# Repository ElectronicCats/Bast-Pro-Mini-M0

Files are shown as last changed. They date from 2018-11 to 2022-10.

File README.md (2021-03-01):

# Bast Pro Mini M0

MX0005

**[OSHW] MX0005 | Certified open source hardware |** [oshwa.org/cert.](https://www.oshwa.org/cert)

<a href="https://electroniccats.com/store/bast-pro-mini-m0/">
  
</a>

Electronic Cats Bast are a complete line of development boards for electronic cats.

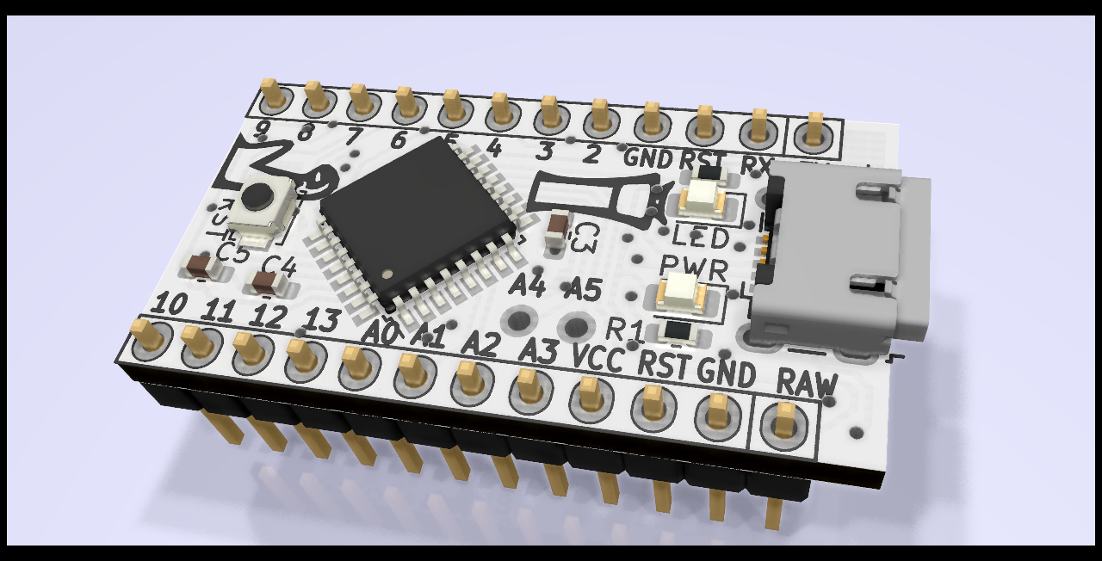
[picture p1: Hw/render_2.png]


Bast Pro Mini M0 is all the best in the world Arduino Pro Mini with a SAMD21 M0+ core, 32 bits of power!, Arduino pro mini pin to pin compatible with a micro USB port.

Electronic Cats invests time and resources providing this open source design, please support Electronic Cats and open-source hardware by purchasing products from Electronic Cats!

Designed by Electronic Cats.

## Installation

While the SAMD21 alone is powerful enough, what truly makes it special is its growing support in the Arduino IDE. With just a couple click's, copies, and pastes, you can add ARM Cortex-M0+-support to your Arduino IDE. 

First of all we'll need to install the Arduino SAMD based boards, to do it you just need to go (Tools > Board > Boards Manager...)

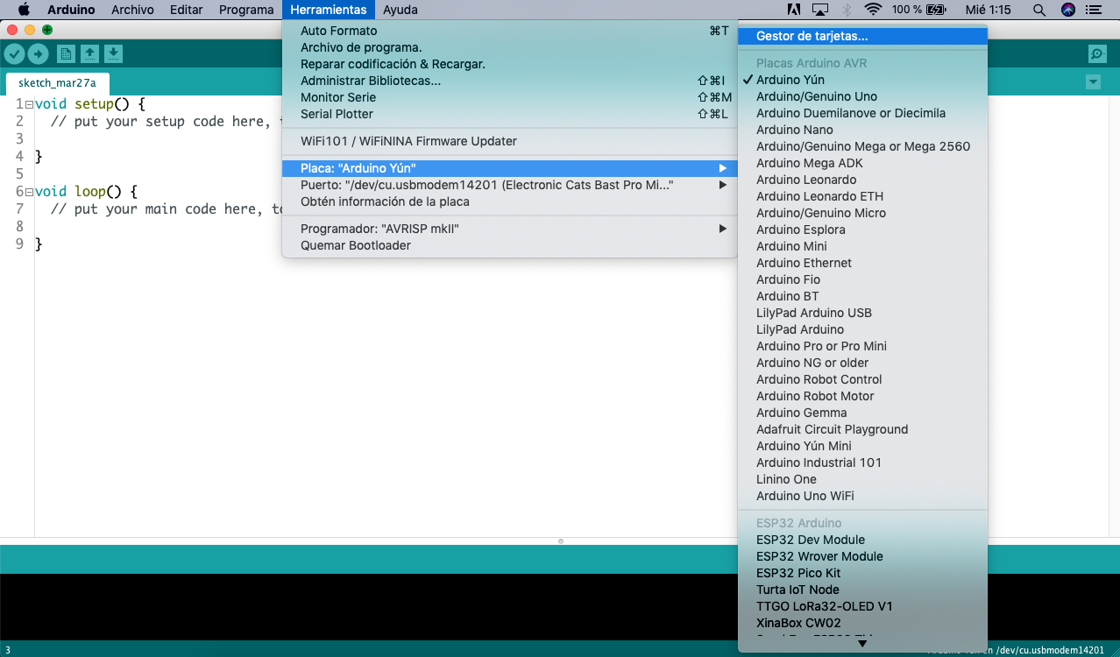
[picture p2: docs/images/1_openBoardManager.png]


And then search for "SAMD"

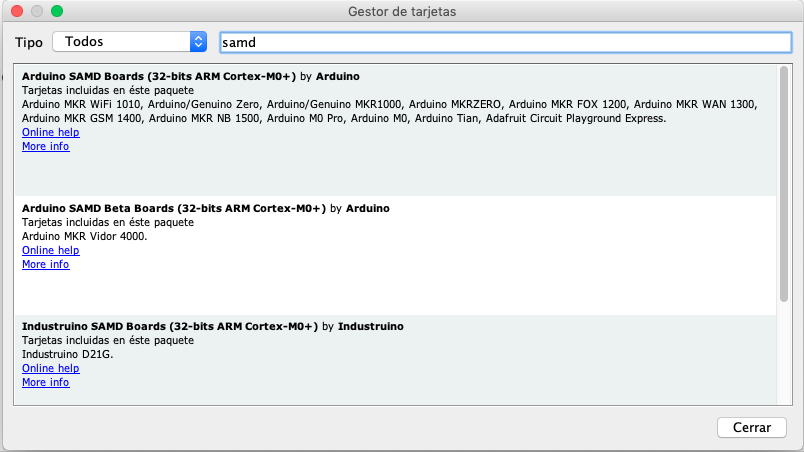
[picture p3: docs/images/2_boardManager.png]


And install the "Arduino SAMD Board (32-bits ARM Cortex M0+)" once you have installed the Arduino SAMD21 core you must proceed installing our boards variants following the next steps:

Open your Arduino preferences (File > Preferences) or (Arduino > Preferences)

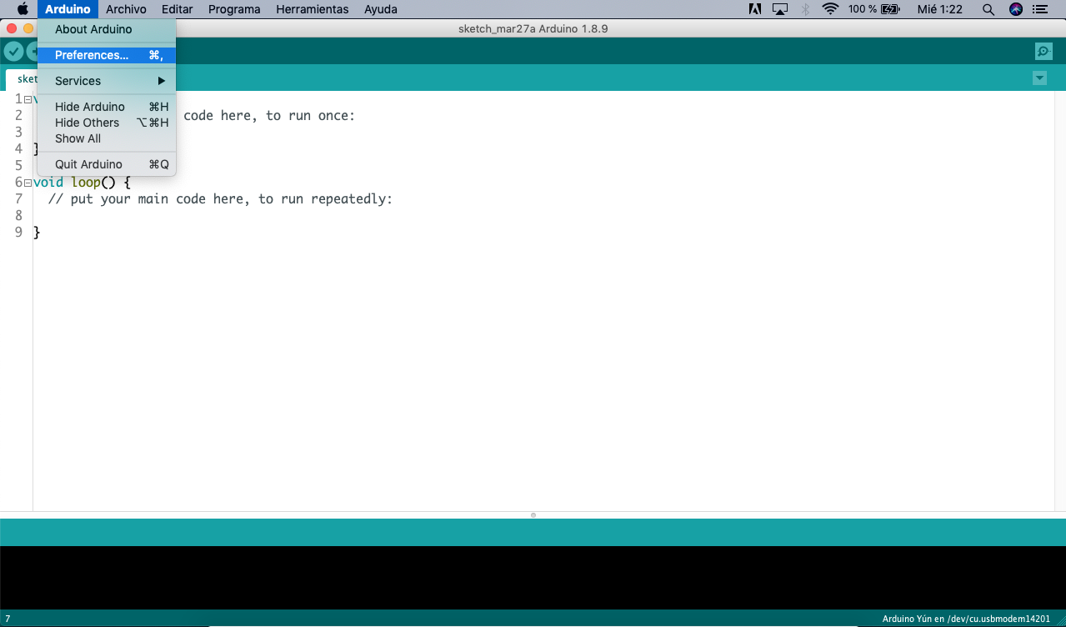
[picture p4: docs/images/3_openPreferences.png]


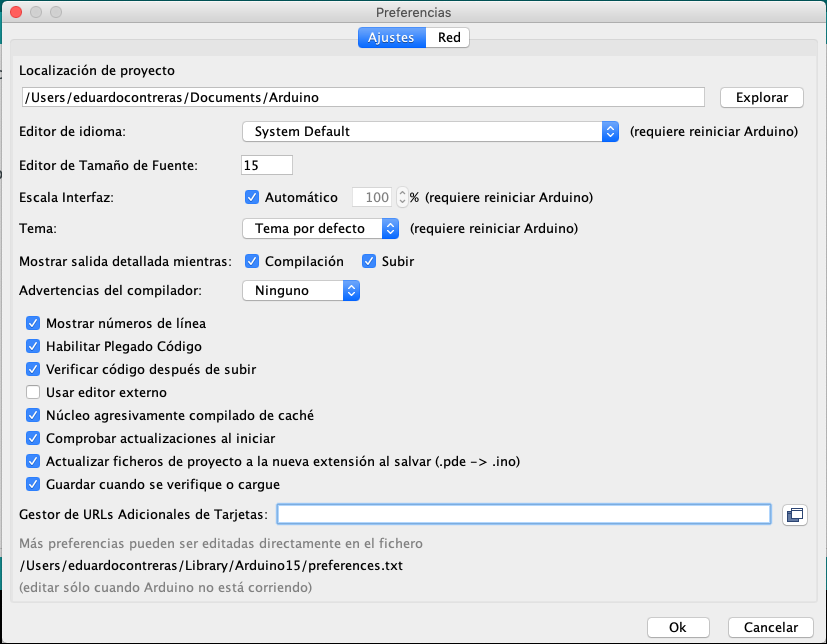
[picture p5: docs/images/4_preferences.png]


You will need to copy the next link into the additional boards manager URL, if you have another link just add a "," before this second link.

`https://electroniccats.github.io/Arduino_Boards_Index/package_electroniccats_index.json
`
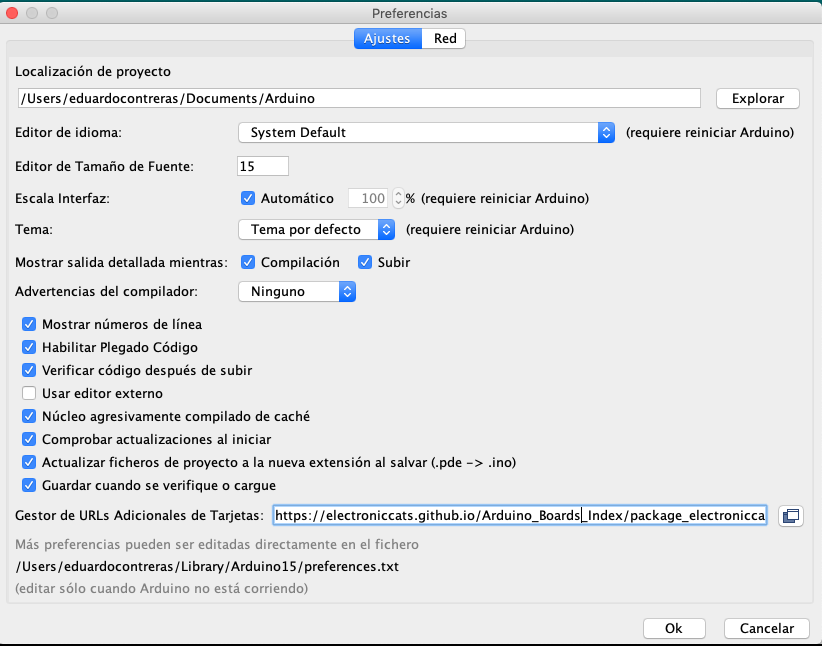
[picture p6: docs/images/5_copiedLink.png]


Then you can click on the OK button to close the preferences panel and continue the installation.

If you did hit "OK", travel back to the Board Manager menu. You should be able to find a new entry for Electronic Cats. If you don't see it, close the board manager and open it again.

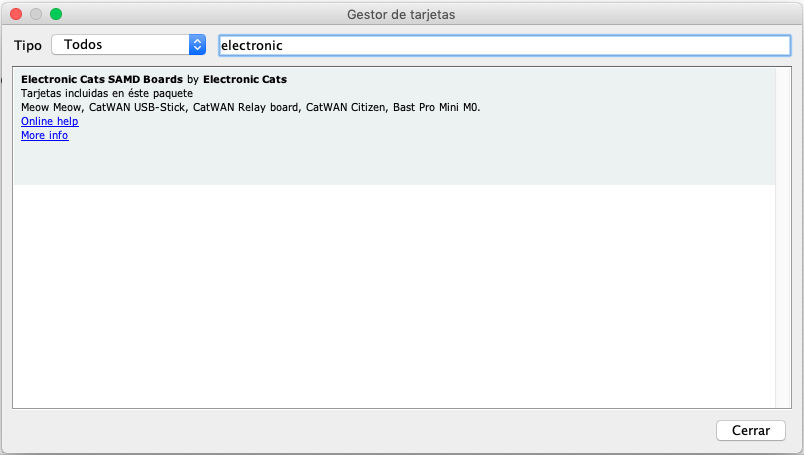
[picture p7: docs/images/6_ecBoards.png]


Click on install and once the boards are installed you should be able to select them on the (Tools > Boards) section.

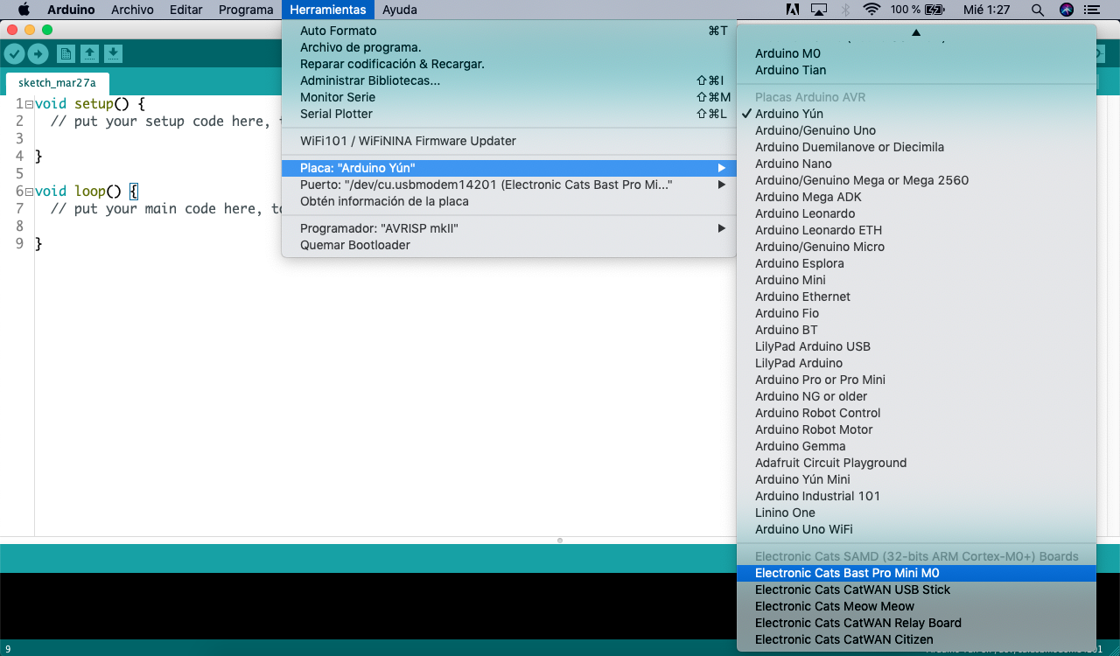
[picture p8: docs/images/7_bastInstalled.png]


So now you can program your Bast Pro Mini M0 as a common arduino!

Test the Blink example and then start prototyping!  

## Driver for windows 7 and 8.1

Zadig image

[Zadig](https://zadig.akeo.ie/) is the recommended tool to install drivers in Windows. The bootloader (4348,55E0) should be installed with WinUSB or libusb-win32 driver.

You can use USB Serial (CDC) driver for default CDC USB stack. If you tried to emulate another type of USB device without changing the PID/VID, you may need to uninstall the device before installing a new driver.

## Pinout

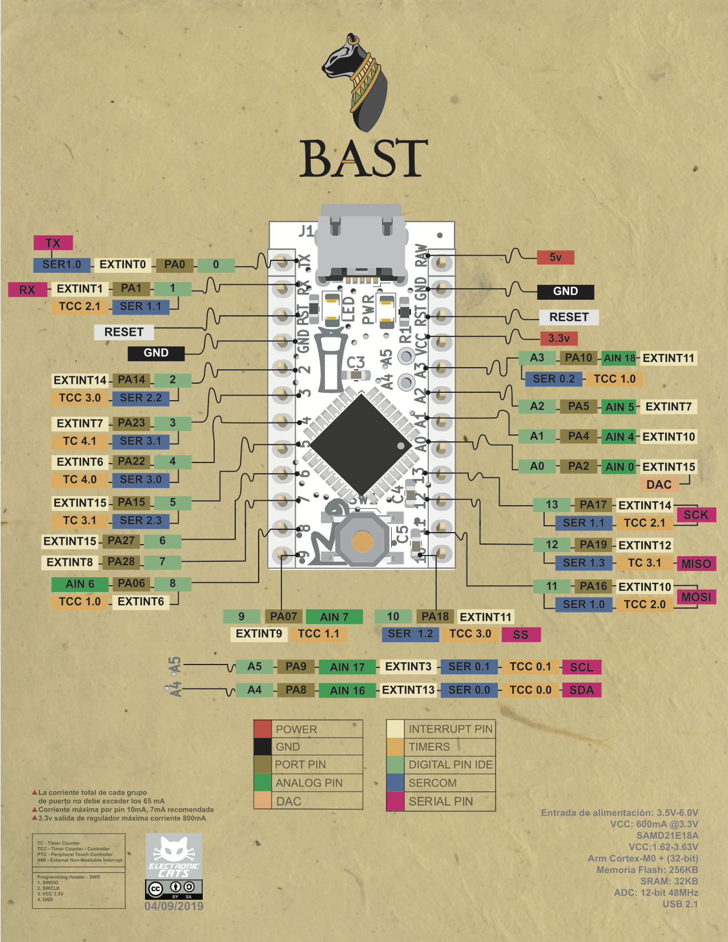
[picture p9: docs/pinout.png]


## License hardware

Hardware released under an CERN Open Hardware Licence v1.2. See the LICENSE_HARDWARE file for more information.

## License Documentation 
<br />Esta obra está bajo una <a rel="license" href="http://creativecommons.org/licenses/by-sa/4.0/">Licencia Creative Commons Atribución-CompartirIgual 4.0 Internacional</a>.

Electronic Cats is a registered trademark, please do not use if you sell these PCBs.

30 Oct 2018

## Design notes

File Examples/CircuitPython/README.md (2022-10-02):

## Ejemplos de codigo en CircuitPython

### Todos los ejemplos estan optimizados para la tarjeta:

## Bast Pro Mini M0.

* blink.py : Enciende y apaga el Led incroporado en la tarjeta.
* i2c_show.py : Muestra todos los pines que pueden ser usados para i2c
* pinout_show.py : Muestra los pines disponibles en la tarjeta.
* uart_show.py : Muestra todos los pines que pueden ser usados para UART.

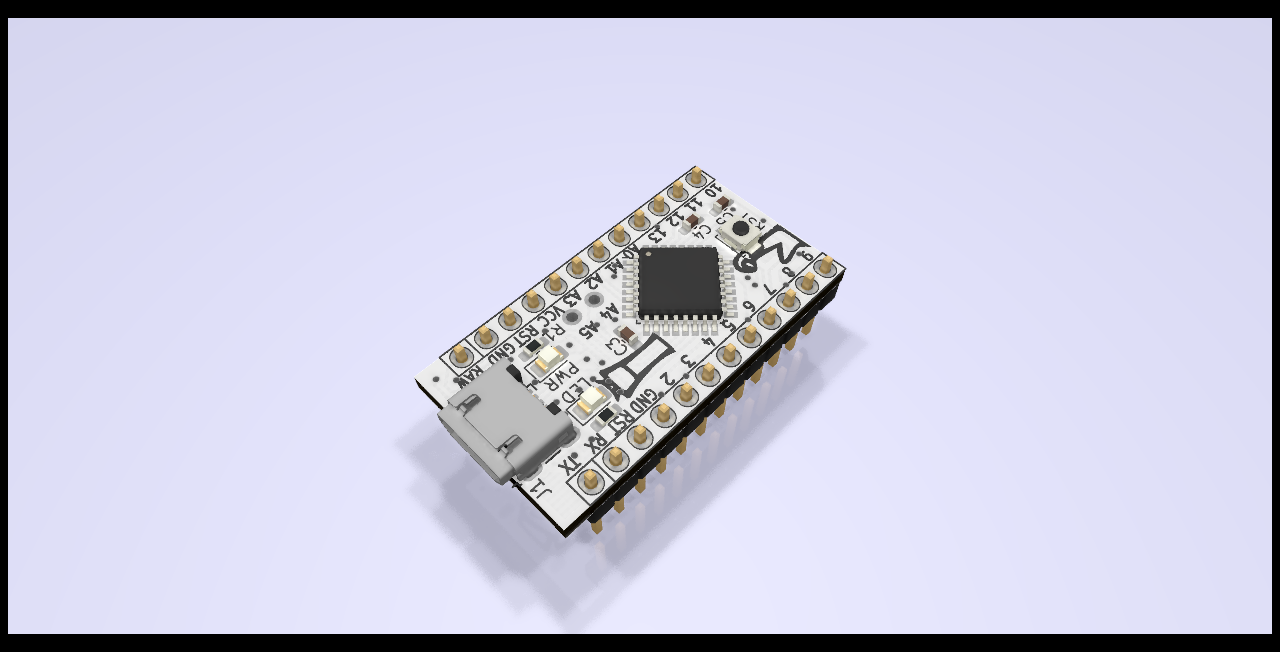
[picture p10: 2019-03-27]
Hw/render_1.png

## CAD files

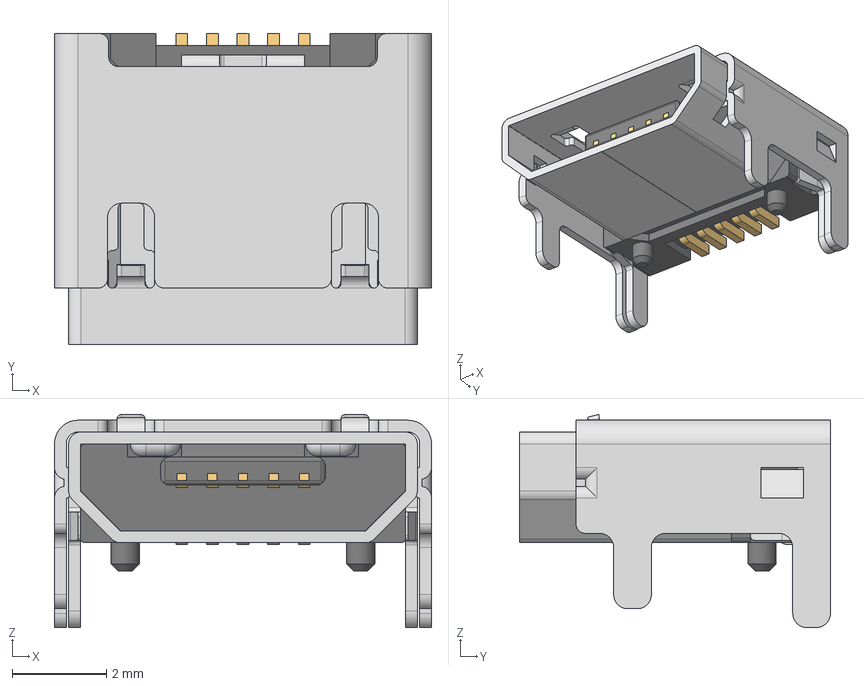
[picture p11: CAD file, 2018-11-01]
Hw/3d/629105150521 (rev1).stp
8.00 x 6.60 x 4.52 mm
629105150521_Housing
629105150521_Pin1 x 4
629105150521_Pin2
629105150521_Shielding2
629105150521_Shielding

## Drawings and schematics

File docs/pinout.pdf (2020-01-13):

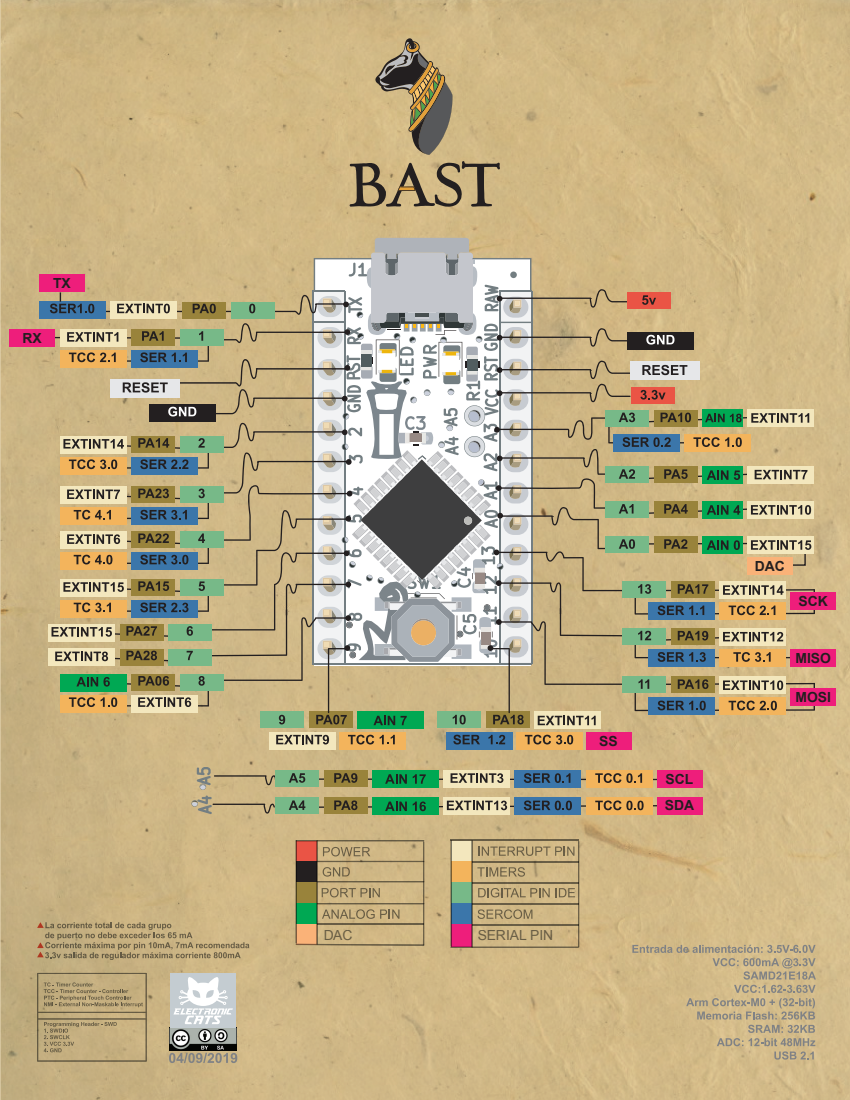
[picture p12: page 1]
SERIAL PIN; SDA; SCL; MISO; SCK; MOSI; DAC

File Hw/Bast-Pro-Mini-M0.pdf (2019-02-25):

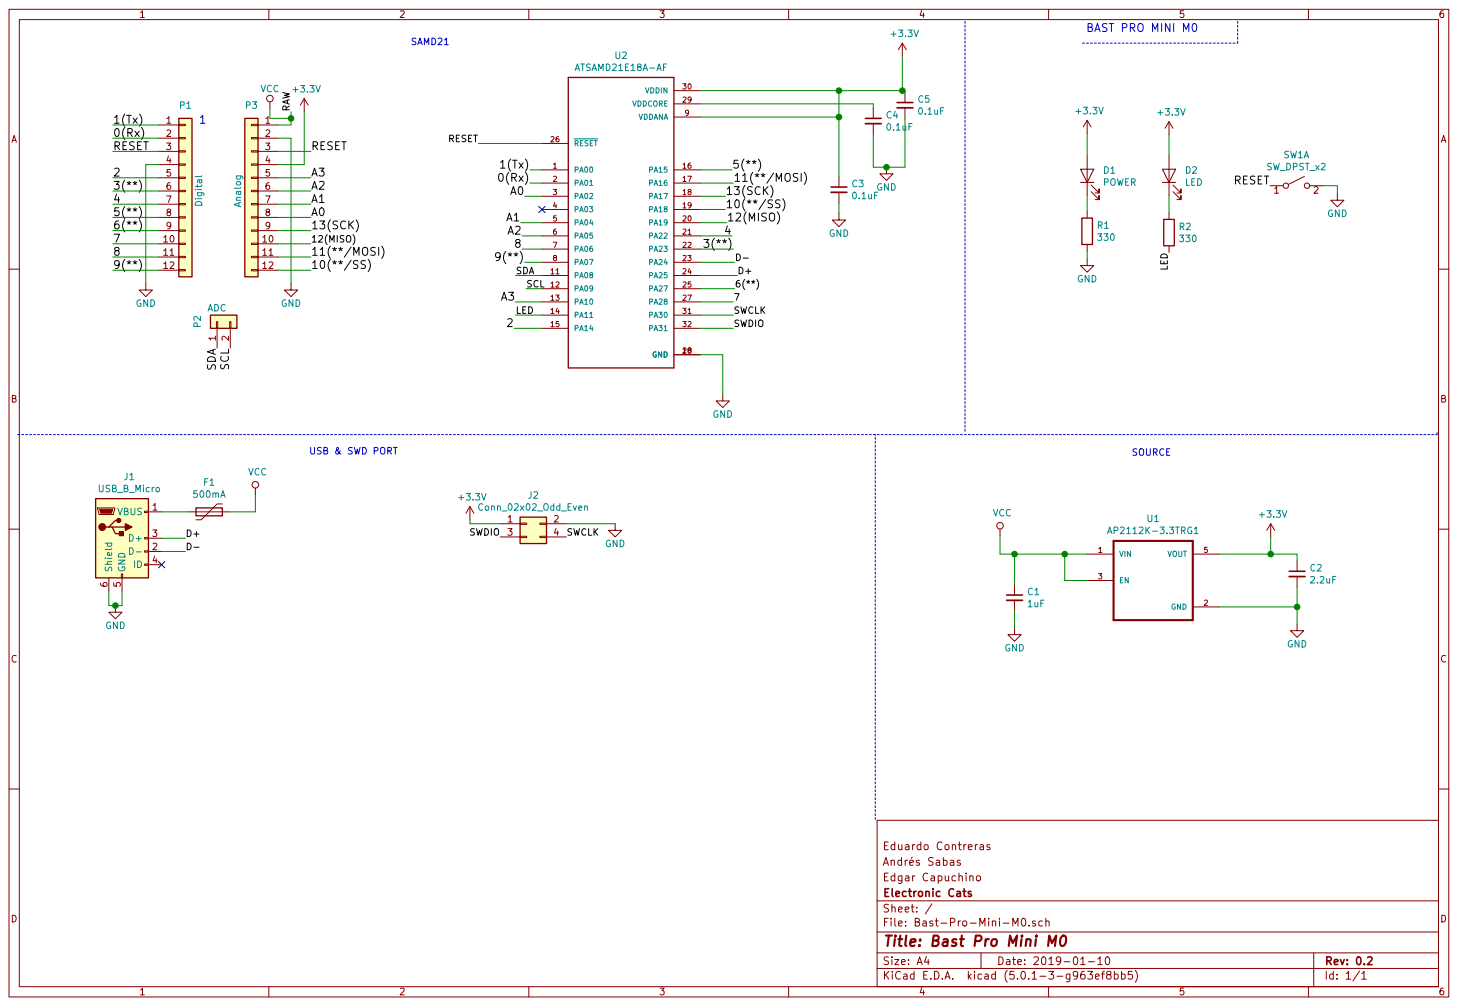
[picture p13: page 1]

12(MISO) 13(SCK) A0A1A2A3 SDA SCL

File: Bast-Pro-Mini-M0.sch Sheet: / Electronic Cats Edgar Capuchino Andrés Sabas Eduardo Contreras

Id: 1/1 Title: Bast Pro Mini M0

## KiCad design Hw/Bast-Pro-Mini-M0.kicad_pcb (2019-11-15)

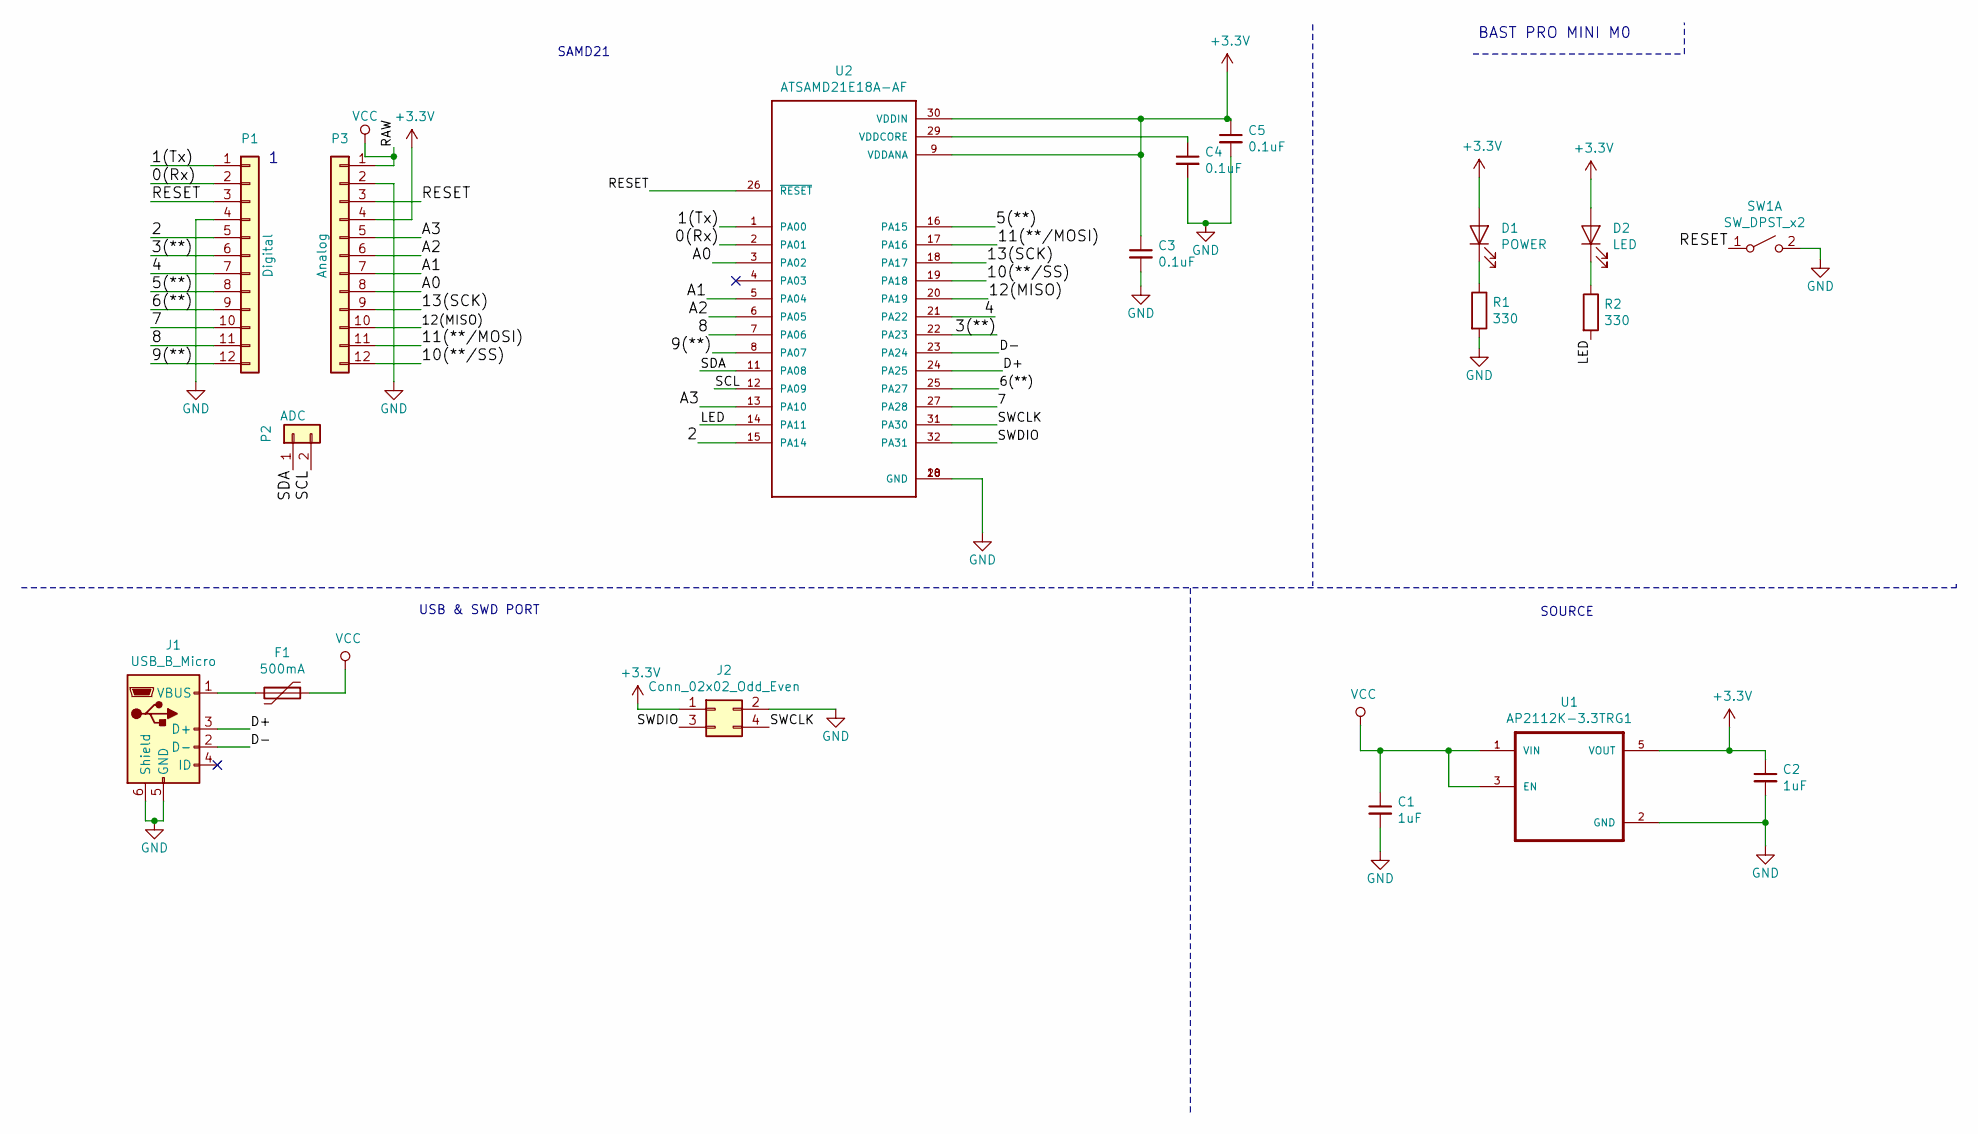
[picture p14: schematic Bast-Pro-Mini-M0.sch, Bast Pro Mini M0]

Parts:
C1, C2: 1uF; C_0603_1608Metric_Pad1.05x0.95mm_HandSolder
C3, C4, C5: 0.1uF; C_0603_1608Metric_Pad1.05x0.95mm_HandSolder
D1: POWER; LED_0805_2012Metric_Pad1.15x1.40mm_HandSolder
D2: LED; LED_0805_2012Metric_Pad1.15x1.40mm_HandSolder
F1: 500mA; Fuse_0805_2012Metric_Pad1.15x1.40mm_HandSolder
J1: USB_B_Micro; U254051N4BH806
J2: Conn_02x02_Odd_Even; PinHeader_2x02_P2.54mm_Vertical_SMD
P1: Digital; PinHeader_1x12_P2.54mm_Vertical
P2: ADC; Socket_Strip_Arduino_1x02
P3: Analog; Socket_Strip_Arduino_1x12
R1, R2: 330; R_0603_1608Metric_Pad1.05x0.95mm_HandSolder
SW1: SW_DPST_x2; SW_SPST_TL3342
U1: AP2112K-3.3TRG1; SOT-23-5
U2: ATSAMD21E18A-AF; TQFP-32_7x7mm_P0.8mm

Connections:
+3V3: C2.1, C3.1, C5.1, D1.2 (A), D2.2 (A), J2.1, P3.4, U1.5 (VOUT), U2.9 (VDDANA), U2.30 (VDDIN)
/0(Rx): P1.2, U2.2 (PA01)
/1(Tx): P1.1, U2.1 (PA00)
/2: P1.5, U2.15 (PA14)
/3(**): P1.6, U2.22 (PA23)
/4: P1.7, U2.21 (PA22)
/5(**): P1.8, U2.16 (PA15)
/6(**): P1.9, U2.25 (PA27)
/7: P1.10, U2.27 (PA28)
/8: P1.11, U2.7 (PA06)
/9(**): P1.12, U2.8 (PA07)
/10(**/SS): P3.12, U2.19 (PA18)
/11(**/MOSI): P3.11, U2.17 (PA16)
/12(MISO): P3.10, U2.20 (PA19)
/13(SCK): P3.9, U2.18 (PA17)
/A0: P3.8, U2.3 (PA02)
/A1: P3.7, U2.5 (PA04)
/A2: P3.6, U2.6 (PA05)
/A3: P3.5, U2.13 (PA10)
/D+: J1.3 (D+), U2.24 (PA25)
/D-: J1.2 (D-), U2.23 (PA24)
/LED: R2.2, U2.14 (PA11)
/RESET: P1.3, P3.3, SW1.1 (A), U2.26 (~RESET~)
/SCL: P2.2, U2.12 (PA09)
/SDA: P2.1, U2.11 (PA08)
/SWCLK: J2.4, U2.31 (PA30)
/SWDIO: J2.3, U2.32 (PA31)
GND: C1.2, C2.2, C3.2, C4.2, C5.2, J1.5 (GND), J1.6 (Shield), J2.2, P1.4, P3.2, R1.2, SW1.2 (B), U1.2 (GND), U2.10 (GND), U2.28 (GND)
unnamed: C4.1, U2.29 (VDDCORE)
unnamed: D1.1 (K), R1.1
unnamed: D2.1 (K), R2.1
unnamed: F1.2, J1.1 (VBUS)
VCC: C1.1, F1.1, P3.1, U1.1 (VIN), U1.3 (EN)

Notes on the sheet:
BAST PRO MINI M0
SAMD21
SOURCE
USB & SWD PORT

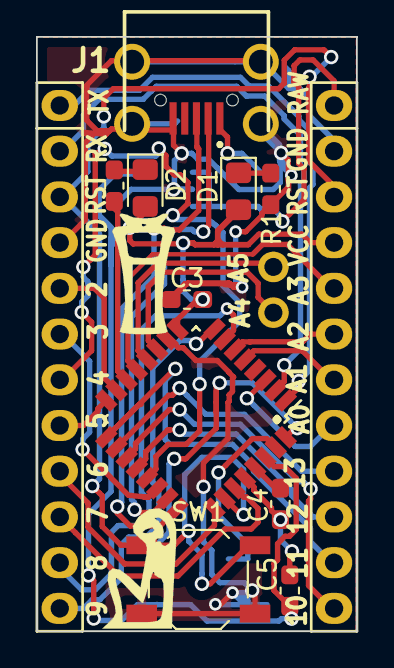
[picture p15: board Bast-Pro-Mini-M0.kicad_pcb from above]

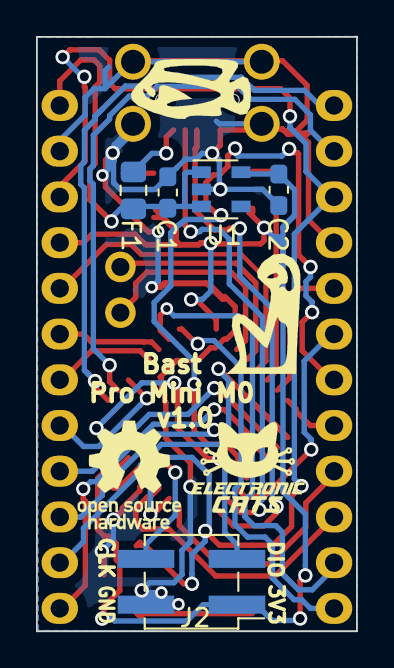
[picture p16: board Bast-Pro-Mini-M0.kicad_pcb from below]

Board: 2 copper layers, 17.8 x 33.0 mm, 18 parts (5 on the bottom side), 33 nets.

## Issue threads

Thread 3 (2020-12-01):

Windows 8.1 no reconoce la tarjeta Bast-Pro-Mini-M0

AngelBNShark, 2020-12-01:
Hola que tal tengo el siguiente conflicto: Al conectar la tarjeta Bast-Pro-Mini-M0 por cualquiera de los puertos USB este lo detecta pero aparece en la seccion de otros dispositivos con un triangulo amarillo y un signo de admiracion, obviamente esto significa que el driver no se instalo, me pueden apoyar para darle solucion a este problema.
Sera que habra que modificar el driver instalado en el ATSAMD21E18 o reconfigurarlo?
Este cambio se puede hacer desde el mismo puerto USB o se tiene que usar el puerto JTAG?

Bueno abro el hilo para dar solucion a esto.
Saludos!
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

sabas1080, 2020-12-01:
Hola @AngelBNShark

Windows 8.1 parece tener bastantes problemas con drivers en general, parece puede ser la firma de drivers segun este hilo, por favor probar y me cuentas https://forum.arduino.cc/index.php?topic=445796.0

AngelBNShark, 2020-12-02:
Gracias por tu respuesta, leó, implemento y comento ;)

AngelBNShark, 2020-12-02:
Hola @sabas1080

segui el procedimiento del link que me compartiste: desactive la firma de controladores de windows, re-instale el paquete de Arduino SAM Boards, conecte la bast pro mini y naranjas, sigue igual :(

sabas1080, 2020-12-02:
@AngelBNShark debes reinstalar arduino IDE y los drivers

sabas1080, 2020-12-02:
@AngelBNShark puedes probar usando https://zadig.akeo.ie/ ? Si no tendras que esperar a que generemos los drivers para Windows 8.1 y versiones pasadas

AngelBNShark, 2020-12-02:
Hola, hoy la conecte a una pc con Windows 7 y tampoco lo instaló.

Unas preguntas:
En que sistemas operativos la han probado?
A tu experiencia con este micro que programador recomiendas o debugger recomiendas para estos micros?

Un gran saludo!!!

AngelBNShark, 2020-12-02:
En Windows 8.1 reinstalé el IDE y el paquete de tarjetas, tampoco dio solución :(

sabas1080, 2020-12-02:
- Linux, Mac y Windows 10 esta probado
- Jlink o Blackmagic para depuracion, tambien hemos usado nuestro DAPCat
- Trata con https://zadig.akeo.ie/ en Windows 7 y Windows 10

AngelBNShark, 2020-12-04:
Hola, trate instalando un drive con "Zadig" y exito! este instala un controlador, pero el ID de Arduino no lo reconoce :'(.
Sigo investigando una solución ;)

Saludos.

AngelBNShark, 2020-12-05:
Hola que tal, ya quedo :D, la solución fue instalar un controlador usando "Zadig" con la opción  "USB Serial (CDC)", no había visto esta opción, funciona bien tanto en windows 7 y como en windows 8.1.

Un gran saludo.

sabas1080, 2020-12-05:
Excelente, gracias @AngelBNShark , voy agregar las instrucciones al README para Windows 7 y Windows 8.1

Closed 2020-12-05.

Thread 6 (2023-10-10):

PWM

NeftaliVenancio, 2023-10-10:
¿Podrían indicarme cuales son los pines habilitados para PWM?

Marcelol52, 2023-10-11:
Hola Neftali,

Los pines que están habilitados en la variante de nuestro core son: 3, 5, 6, 9 y 10.

Espero te sea de utilidad.

NeftaliVenancio, 2023-10-13:
Podras compartirme la documentación para habilitar 5 y 6 por favor.

Marcelol52, 2023-10-13:
Hola Neftali,

Si estas usando el IDE de Arduino en Windows, puedes encontrar la variante en la ruta: \AppData\Local\Arduino15\packages\electroniccats\hardware\samd\2.1.2\variants\bast_pro_mini_m0\variant.cpp

Para otros sistemas operativos la ruta es similar.

Marcelol52, 2023-10-13:
Hola Neftali,

Si estas usando el IDE de Arduino en Windows, puedes encontrar la variante en la ruta: \AppData\Local\Arduino15\packages\electroniccats\hardware\samd\2.1.2\variants\bast_pro_mini_m0\variant.cpp

Para otros sistemas operativos la ruta es similar.

Actualmente no tenemos documentación acerca de esto para la tarjeta, estamos trabajando en ellos. Pero puedes referirte al manual de usuario u hoja de datos del microcontrolador y encontrar la información pertinente ahí.

Marcelol52, 2023-10-16:
<html>
Hola Neftali,

Después de revisar más la variante encontré que estos pines son los que pueden generar PWM, en la tabla también te comparto el reloj que usa cada uno. Adjunté también dos imágenes que muestran como hay que modificar la variante para que  se pueda generar el PWM. El proceso es sencillo, es cambiar ya sea el reloj existente o la etiqueta de 'NOT_ON_TIMER' por el reloj que viene en la tabla. Hice algunas pruebas con nuestro osciloscopio y la señal se genera bien.  Espero esto te sea de más ayuda, Cualquier problema no dudes en contactarnos de nuevo.

<body>
<!--StartFragment--><google-sheets-html-origin><style type="text/css"><!--td {border: 1px solid #cccccc;}br {mso-data-placement:same-cell;}--></style>

Port | PIN | MCU | TC/TCC
-- | -- | -- | --
A | 3 | PA23 | TC4_CH1
A | 4 | PA22 | TC4_CH0
A | 5 | PA15 | TC3_CH1
A | 8 | PA06 | TCC1_CH0
A | 9 | PA07 | TCC1_CH1
A | 10 | PA18 | TC3_CH0
A | 12 | PA19 | TC3_CH1
A | 13 | PA17 | TCC2_CH1

<!--EndFragment-->
</body>
</html>

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

NeftaliVenancio, 2023-10-18:
Gracias

NeftaliVenancio, 2024-01-17:
Tendras algun codigo de ejemplo para usar los pines 9 y 10, el unico que me esta respondiendo corectamente es el A0 usando el DAC

Marcelol52, 2024-01-19:
Te comparto abajo el código que utilicé para probar el PWM en los pines 9 y 10. Solo recurda que se tiene que hacer un cambio el la variante de la tarjeta para activar el PWM. Solo se tiene que cambiar el reloj que se está usando para ese PIN. Si estas usando el IDE de Arduino, puedes encontrar la variante para modificarla en la ruta: \AppData\Local\Arduino15\packages\electroniccats\hardware\samd\2.1.2\variants\bast_pro_mini_m0\variant.cpp

Original
```
 // 9 - PA07 -  GPIO - PWM
  { PORTA,  7, PIO_MULTI, (PER_ATTR_DRIVE_STD|PER_ATTR_TIMER_STD), (PIN_ATTR_DIGITAL|PIN_ATTR_TIMER), TCC1_CH0, No_ADC_Channel, EXTERNAL_INT_7, GCLK_CCL_NONE }, // TCC0/WO[1]

  // SPI SERCOM3
  // 10 - PA18 -  GPIO - PWM - SS(SPI)
  { PORTA,  18, PIO_SERCOM, (PER_ATTR_DRIVE_STD|PER_ATTR_TIMER_STD), (PIN_ATTR_DIGITAL|PIN_ATTR_TIMER|PER_ATTR_SERCOM_ALT), TCC0_CH0, No_ADC_Channel, EXTERNAL_INT_2, GCLK_CCL_NONE },  // TCC0/WO[0]
```
Cambio para hacer funcionar el PWM
```
  // 9 - PA07 -  GPIO - PWM
  { PORTA,  7, PIO_MULTI, (PER_ATTR_DRIVE_STD|PER_ATTR_TIMER_STD), (PIN_ATTR_DIGITAL|PIN_ATTR_TIMER), TCC1_CH1, No_ADC_Channel, EXTERNAL_INT_7, GCLK_CCL_NONE }, // TCC0/WO[1]

  // SPI SERCOM3
  // 10 - PA18 -  GPIO - PWM - SS(SPI)
  { PORTA,  18, PIO_SERCOM, (PER_ATTR_DRIVE_STD|PER_ATTR_TIMER_STD), (PIN_ATTR_DIGITAL|PIN_ATTR_TIMER|PER_ATTR_SERCOM_ALT), TC3_CH0, No_ADC_Channel, EXTERNAL_INT_2, GCLK_CCL_NONE },  // TCC0/WO[0]
```
Código
```

//const int led_pwm = 9 ;	// Definimos la salida PWM
const int led_pwm = 10 ;	// Definimos la salida PWM
int adc_nuevo = 0 ;   	// Usamos entrada ADC en pin A0
int adc_viejo = 0 ;   	// Guardamos la última lectura del ADC

void setup() {
  // Inicializamos el puerto serie
  Serial.begin(9600);

  // Configuramos pwm como salida
  pinMode(led_pwm, OUTPUT) ;
}

void loop() {
  // Leemos el valor del ADC en el pin A0  usando un POT de 10k
  adc_nuevo  = analogRead(A0) ;

  // Ajustamos el valor leido en A0 para adaptarlo al rengo
  // del PWM. Se adapta la escala de 0-1023 a 0-255
  adc_nuevo = map(adc_nuevo, 0, 1023, 0, 255);

  if (adc_nuevo != adc_viejo) {
    // Actualiza la lectura del ADC
    adc_viejo = adc_nuevo;

    // Envia el valor actual al puerto serie
    Serial.println(adc_nuevo);

    // Envia el valor adaptado al PWM
    analogWrite(led_pwm, adc_nuevo);
  }
}
```

Espero esta información te sea de ayuda, si tienes más dudas no dudes en contactarnos de nuevo.

NeftaliVenancio, 2024-01-19:
ok, por defecto como viene el core a la hora instalara la tarjeta ¿No se puede usar ningún pin como PWM sin necesidad de hacer la modificación?

Marcelol52, 2024-01-19:
Lo pines que pueden generar PWM con el core como está son: pines digitales, 1 y 13. En cuanto a los pines análogos, estos no generan como tal un PWM, pueden regular la salida de voltage pero no es a traves de una regulación del ancho del pulso.

NeftaliVenancio, 2024-01-19:
¿todos los analógicos pueden regular el voltaje o solo el A0 a través del DAC?

Marcelol52, 2024-01-19:
El A0 es el unico que tiene un DAC para hacer esa regulación de voltage. Y realizando más se puede hacer PWM con A1 también con el core como está. En total serian pines digitals D1,D13,A1 y el A0 con DAC.

Closed 2023-10-16.

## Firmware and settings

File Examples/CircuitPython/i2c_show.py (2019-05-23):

#Muestra los pines donde se puede crear
#una instancia i2c
import board
import busio
from microcontroller import Pin

def is_hardware_I2C(scl, sda):
    try:
        p = busio.I2C(scl, sda)
        p.deinit()
        return True
    except ValueError:
        return False
    except RuntimeError:
        return True


def get_unique_pins():
    #exclude = ['NEOPIXEL', 'APA102_MOSI', 'APA102_SCK']
    exclude = []
    pins = [pin for pin in [
        getattr(board, p) for p in dir(board) if p not in exclude]
            if isinstance(pin, Pin)]
    unique = []
    for p in pins:
        if p not in unique:
            unique.append(p)
    return unique


for scl_pin in get_unique_pins():
    for sda_pin in get_unique_pins():
        if scl_pin is sda_pin:
            continue
        else:
            if is_hardware_I2C(scl_pin, sda_pin):
                print("SCL pin:", scl_pin, "\t SDA pin:", sda_pin)
            else:
                pass

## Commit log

2018-09-28 Schematic initial
    [Croketa.kicad_pcb, Croketa.sch]
2018-09-29 Schematic finished
    [Croketa.sch]
2018-09-29 Schematic finished, now yes
    [Croketa.sch]
2018-10-02 first components places
    [Croketa.kicad_pcb, Croketa.sch]
2018-10-03 Second arrangement of components in pcb
    [Croketa.kicad_pcb, Croketa.sch]
2018-10-04 Add logos
    [Croketa.kicad_pcb]
2018-10-07 Remove leds and change pins I2C
    [Croketa.sch]
2018-10-07 Pre router
    [Croketa.kicad_pcb]
2018-10-08 V0.2 Fix Connection
    [Croketa.sch]
2018-10-10 Dimensions of Bast Pro Mini M0
    [Croketa.kicad_pcb, _saved_Croketa.sch]
2018-10-16 Add art
    [Croketa.kicad_pcb, _saved_Croketa.sch]
2018-10-30 New pcb's Bast
    [Croketa.kicad_pcb, Croketa.sch]
2018-10-30 Rename files Bast Pro Mini M0
    [Bast-Pro-Mini-M0.kicad_pcb, Bast-Pro-Mini-M0.sch]
2018-10-31 first design
    [Bast-Pro-Mini-M0.kicad_pcb]
2018-10-31 Bast Pro Mini (ultimate revision)
    [Bast-Pro-Mini-M0.kicad_pcb]
2018-10-31 Bast Pro Mini (utimate revision) (Now yes)
    [Bast-Pro-Mini-M0.kicad_pcb]
2018-11-01 Bast Pro Mini M0 add 3d model usb
    [629105150521 (rev1).stp, Bast-Pro-Mini-M0.kicad_pcb, _saved_Bast-Pro-Mini-M0.sch]
2018-11-01 Add gebers rules
    [Bast-Pro-Mini-M0.kicad_pcb]
2018-11-01 silkscreen number pins
    [Bast-Pro-Mini-M0.kicad_pcb]
2018-11-01 Fix details
    [Bast-Pro-Mini-M0.kicad_pcb, _saved_Bast-Pro-Mini-M0.sch]
2018-11-01 update no changes
    [Bast-Pro-Mini-M0.kicad_pcb]
2018-11-01 label v0.1 add
    [Bast-Pro-Mini-M0.kicad_pcb]
2018-11-09 bast revision
    [Bast-Pro-Mini-M0.kicad_pcb, Bast-Pro-Mini-M0.sch]
2018-11-10 Fix tracks and update revision
    [Bast-Pro-Mini-M0.kicad_pcb]
2018-11-10 Fix vias, add version on board
    [Bast-Pro-Mini-M0.kicad_pcb]
2018-11-28 Update tracks
    [Bast-Pro-Mini-M0.kicad_pcb]
2019-01-10 Add BOM
    [Bast-Pro-Mini-M0.sch]
2019-02-25 bump :)
    [Bast-Pro-Mini-M0.sch]
2019-03-27 MOve hardware to its folder
    [629105150521 (rev1).stp, Bast-Pro-Mini-M0.kicad_pcb, Bast-Pro-Mini-M0.sch]
2019-03-28 Change type of button
    [Bast-Pro-Mini-M0.kicad_pcb, Bast-Pro-Mini-M0.sch]
2019-03-28 fix traces
    [Bast-Pro-Mini-M0.kicad_pcb]
2019-05-23 Add Circuit Python examples
2019-07-22 Change caps
    [Bast-Pro-Mini-M0.sch]
2019-11-15 Update USB v1.0
    [Bast-Pro-Mini-M0.kicad_pcb, Bast-Pro-Mini-M0.sch]
2019-11-15 Update V1.0 silkscreen
    [Bast-Pro-Mini-M0.kicad_pcb]
